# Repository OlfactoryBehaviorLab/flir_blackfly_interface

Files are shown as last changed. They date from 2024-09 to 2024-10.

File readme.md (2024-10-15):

# Flir Blackfly S Interface Board

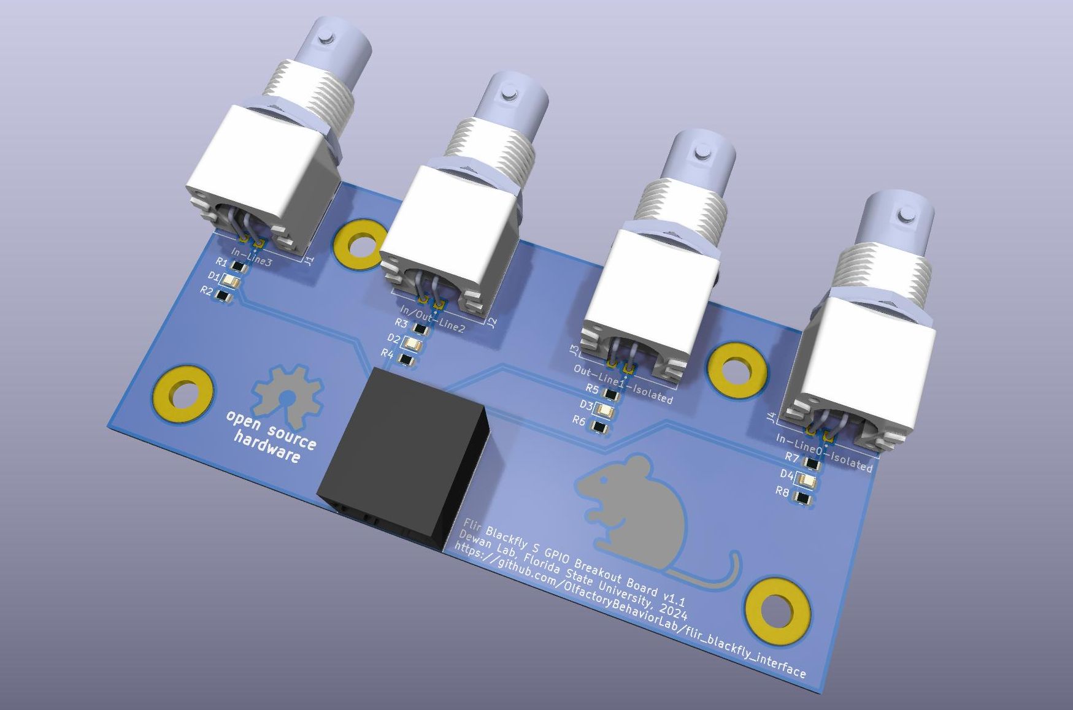
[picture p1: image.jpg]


The Flir Blackfly S series of cameras have a GPIO interface that is exposed via a military-style DIN connector. The FSU Psychology Instrument Development shop generously attached a section of Ethernet cable to the DIN connector. For flexibility, we attached a RJ-45 connector to the opposite end of the cable. Our behavioral controllers expose TTL-level IO via a series of BNC connectors. To facilitate easy connection of our behavioral controller IO to the camera GPIO, we created a small RJ-45 to BNC adapter board.

## Design

The board has a very simple design that connects the RJ-45 pins to the BNC outputs. Two of the GPIO pins are opto-isolated inside the camera. These two GPIO pins and their associated BNC connectors are connected to their own ground plane that returns to the opto-isolated ground connection.

The other two GPIO pins are not opto-isolated and are connected to the power ground of the camera. These two GPIO pins and their associated BNC connectors return via a separate ground plane connected to the power ground.

The board is setup for active **HIGH** inputs. Each input is pulled low using 1k resistors.

Four, M4-sized mounting holes are placed on the board for convenience.

## License

This project is licensed under GNU General Public License v3.0. You can find the included copy of the license [here](LICENSE). For more information about the license and its terms, please visit [SPDX](https://spdx.org/licenses/GPL-3.0-or-later.html)

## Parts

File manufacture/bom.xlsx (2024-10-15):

Designator | Footprint | Quantity | Value | LCSC Part # |  | Source V | Forward V | Forward I | Resistance | V/I=R
D1, D2, D3, D4 | 805 | 4 | LED | C84256 |  | 5 | 2 | 0.025 | 120
J1 | LINX_CONBNC002 | 1 | In-Line3 | DNP
J2 | LINX_CONBNC002 | 1 | In/Out-Line2 | DNP
J3 | LINX_CONBNC002 | 1 | Out-Line1-Isolated | DNP
J4 | LINX_CONBNC002 | 1 | In-Line0-Isolated | DNP
J5 | RJ45_Amphenol_54602-x08_Horizontal | 1 | RJ45 | DNP
OSHW_COPPER_1 | OSHW_COPPER_10MM | 1 | VAL** | DNP
R1, R3, R5, R7 | 805 | 4 | 1k | C17513
R2, R4, R6, R8 | 805 | 4 | 120 | C17437 | Calculate based off of paramaters for D1-D4 part

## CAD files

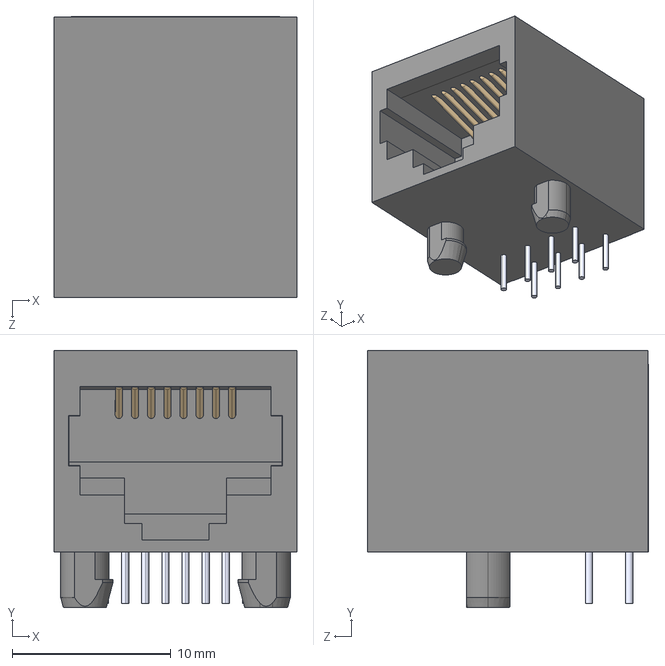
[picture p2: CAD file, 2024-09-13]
kicad_project/parts/54602_908LF/54602-908LF.step
15.3 x 16.2 x 17.7 mm

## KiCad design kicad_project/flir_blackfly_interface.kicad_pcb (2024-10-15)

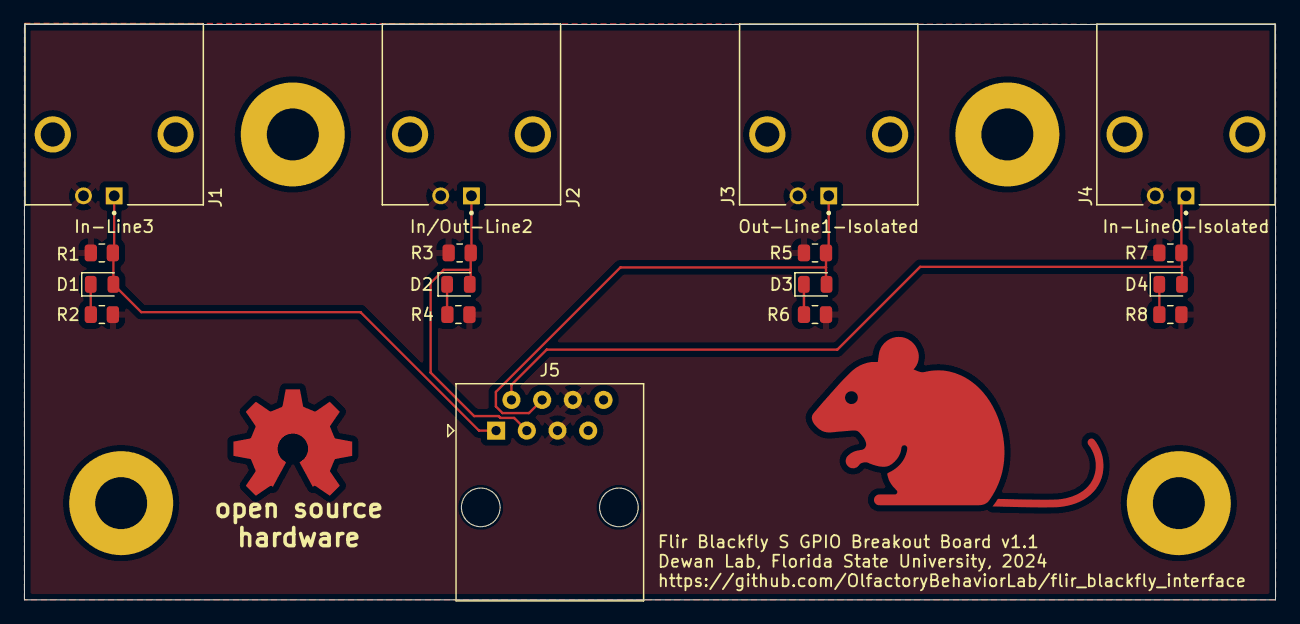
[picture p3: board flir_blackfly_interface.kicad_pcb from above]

Board: 2 copper layers, 103.5 x 47.6 mm, 22 parts (0 on the bottom side), 9 nets.

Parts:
D1, D2, D3, D4: LED; LED_0805_2012Metric
H1, H2, H3, H4: MountingHole_Pad; MountingHole_4.3mm_M4_Pad
J1: In-Line3; LINX_CONBNC002
J2: In/Out-Line2; LINX_CONBNC002
J3: Out-Line1-Isolated; LINX_CONBNC002
J4: In-Line0-Isolated; LINX_CONBNC002
J5: RJ45; RJ45_Amphenol_54602-x08_Horizontal
OSHW_COPPER_1: VAL**; OSHW_COPPER_10MM
R1, R3, R5, R7: 1k; R_0805_2012Metric
R2, R4, R6, R8: R_Small_US; R_0805_2012Metric

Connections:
Input(Line3): D1.2 (A), J1.1 (In), J5.1, R1.1
Input/Output(Line2): D2.2 (A), J2.1 (In), J5.3, R3.1
unnamed: D1.1 (K), R2.1
unnamed: D2.1 (K), R4.1
unnamed: D4.1 (K), R8.1
unnamed: D3.1 (K), R6.1
OptoGround: J1.2 (Ext), J2.2 (Ext), J3.2 (Ext), J4.2 (Ext), J5.5, J5.6, R1.2, R2.2, R3.2, R4.2, R5.2, R6.2, R7.2, R8.2
OptoInput(Line0): D4.2 (A), J4.1 (In), J5.2, R7.1
OptoOut(Line1): D3.2 (A), J3.1 (In), J5.4, R5.1

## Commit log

2024-09-12 Initial commit; first schematic
    [flir_blackfly_interface.kicad_pcb, flir_blackfly_interface.kicad_sch]
2024-09-13 Finished schematic layout; added footprints; added parts to board
    [flir_blackfly_interface.kicad_pcb, flir_blackfly_interface.kicad_sch]
2024-09-13 V1 Board Layout
    [flir_blackfly_interface.kicad_pcb]
2024-09-13 Added 3D model to RJ45 Jack
    [54602-908LF.step, flir_blackfly_interface.kicad_pcb]
2024-09-13 Add text description to board; resize PCB
    [flir_blackfly_interface.kicad_pcb]
2024-09-13 Add mounting holes
    [flir_blackfly_interface.kicad_pcb, flir_blackfly_interface.kicad_sch]
2024-09-13 Add OSHW badge and mouse footprint
2024-09-13 Add OSHW badge, mouse footprint, fix typo in board text
    [flir_blackfly_interface.kicad_pcb]
2024-09-15 Move KiCad project to clean up repository
    [54602-908LF.step, flir_blackfly_interface.kicad_pcb, flir_blackfly_interface.kicad_sch]
2024-09-15 New LEDs and Transistors
    [flir_blackfly_interface.kicad_sch]
2024-10-15 Remove transistors, start laying out LED and resistors
    [flir_blackfly_interface.kicad_pcb, flir_blackfly_interface.kicad_sch]
2024-10-15 Finish laying out LEDs, reado logos, update versions
    [flir_blackfly_interface.kicad_pcb, flir_blackfly_interface.kicad_sch]
2024-10-15 Rename folder, remove old files
    [54602-908LF.step, flir_blackfly_interface.kicad_pcb, flir_blackfly_interface.kicad_sch]
2024-10-15 Add manufacturing files
    [bom.xlsx, designators.csv, positions.csv]
